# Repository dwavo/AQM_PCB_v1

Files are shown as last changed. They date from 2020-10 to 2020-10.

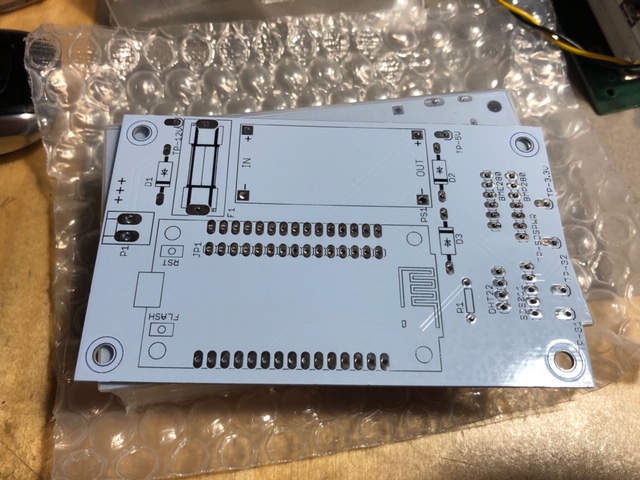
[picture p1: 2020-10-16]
robins egg boards.jpeg

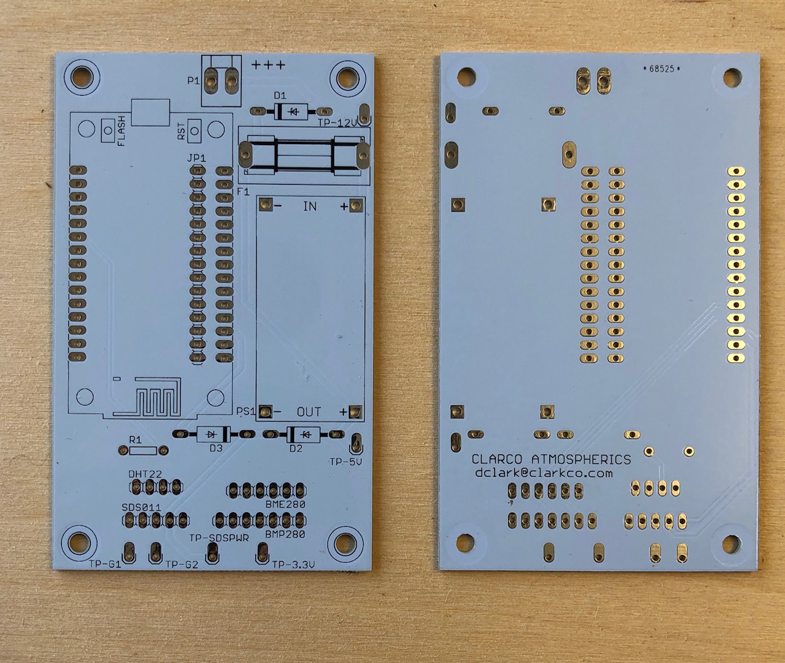
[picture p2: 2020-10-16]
pcb front back.jpg

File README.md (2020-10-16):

# AQM_PCB_v1

Thu Oct 15 19:47:02 PDT 2020

printed circuit board from kevin - sent to china for production.  We did version zero on an 'other mill'.  It proved to be a little too fickle. 

This is the first commercially spun pcb board for AQM luft.data project, now known as sensor community: https://sensor.community/ 

CA design PCB-v1 supports NodeMCUv2 and NodeMCUv3 esp8266 microcontroller.  

Set up with DHT and SDS011 sensors, also supports BM*280; and PMSx003 series sniffers.  P1 allows soldering screw terminals or pigtail, with positive shown as +++.  

Top diode (D1) is for reverse polarity protection.  Fusex at .25 Amp.  dc:buck (LM2596) allows external power source of  9-24V dc source (old wall warts) for long runs (over 5 meters).  This solves the potential low voltage problem of driving the 5v fan on the SDS011.  

Using two 1A 40V Shottky diodes (D2,D3) to protect computer if usb and external power are applied at the same time. Test points added for ground, 5v and 3.3v.  

When building these, adjust the lM2596 to 5v at the test point.  Put black fingernail polish or hot glue and label the power converter "5V".    

A second version is contemplated, which will allow mounting the SDS011 on the same board.   
 
comments: dclark@clarkco.com

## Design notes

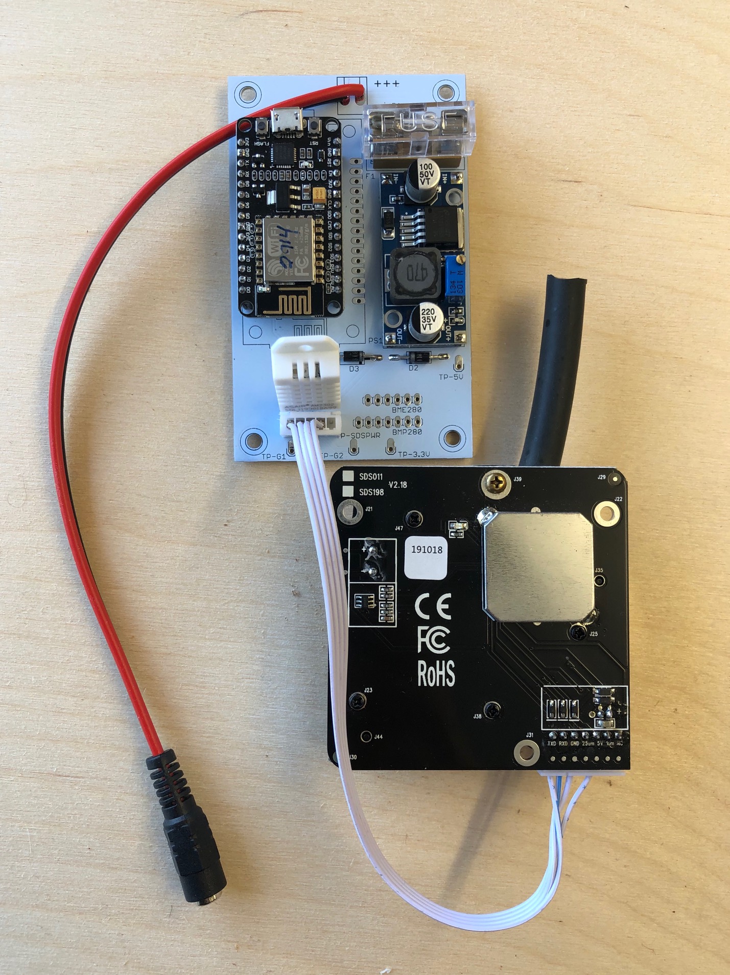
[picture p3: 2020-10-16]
pcb 2.jpg

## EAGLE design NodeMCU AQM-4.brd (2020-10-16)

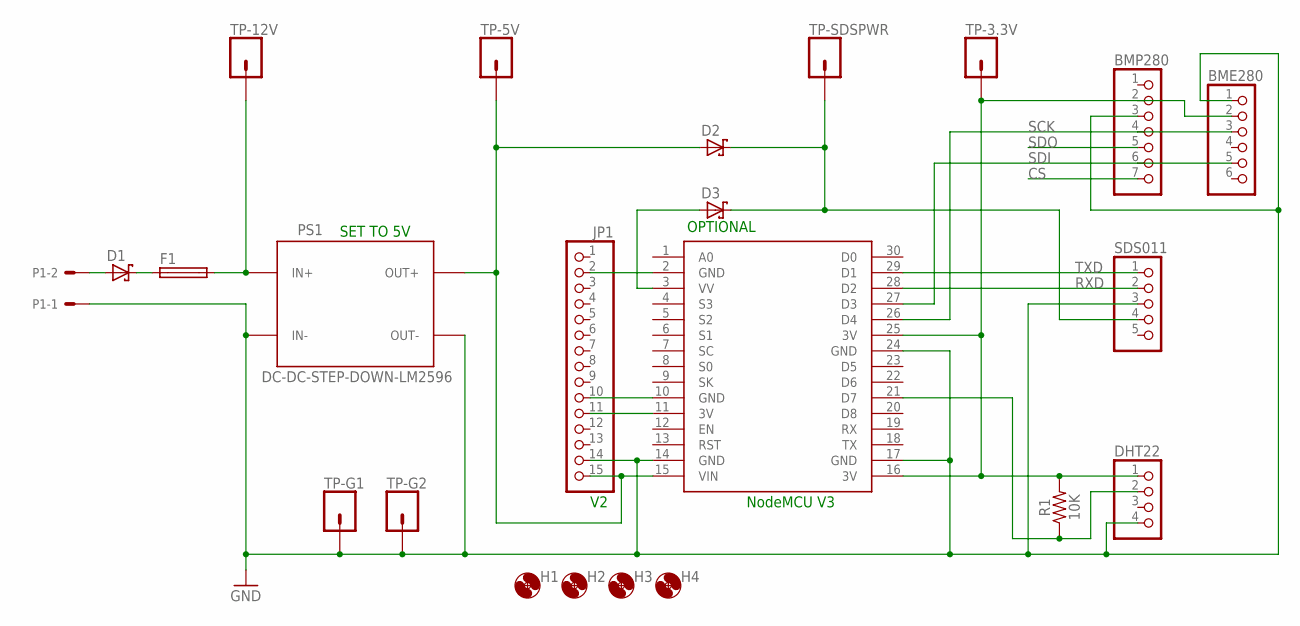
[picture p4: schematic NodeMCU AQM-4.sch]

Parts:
BME280: PINHD-1X6; 1X06
BMP280: PINHD-1X7; 1X07
D1, D2, D3: SCHOTTKY-DIODEF126Z12; DIODE_F126Z12
DHT22: PINHD-1X4; 1X04
F1: SH22,5A
H1, H2, H3, H4: MOUNT-HOLE3.6; 3,6
JP1: PINHD-1X15; 1X15
P1: KK-156-2
PS1: DC-DC-STEP-DOWN-LM2596
R1: 10K; AXIAL-0.3
SDS011: PINHD-1X5; 1X05
TP-3.3V, TP-5V, TP-12V: CONN_01OFFSET; 1X01_OFFSET
TP-G1, TP-G2: CONN_01OFFSET; 1X01_OFFSET
TP-SDSPWR: CONN_01OFFSET; 1X01_OFFSET
U$1: NODEMCU

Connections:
3V3: BME280.2, BMP280.2, DHT22.1, JP1.11, R1.P$2 (2), TP-3.3V.1, U$1.11 (3V), U$1.16 (3V), U$1.25 (3V)
CS: BMP280.7
GND: BME280.1, BMP280.3, DHT22.4, JP1.2, JP1.10, JP1.14, P1.1, PS1.IN-, PS1.OUT-, SDS011.3, TP-G1.1, TP-G2.1, U$1.2 (GND), U$1.10 (GND), U$1.14 (GND), U$1.17 (GND), U$1.24 (GND)
unnamed: D2.A (C), JP1.15, PS1.OUT+, TP-5V.1, U$1.15 (VIN)
unnamed: D3.A (C), U$1.3 (VV)
unnamed: D1.A (C), P1.2
unnamed: D1.C (A), F1.1
unnamed: F1.2, PS1.IN+, TP-12V.1
unnamed: DHT22.2, R1.P$1 (1), U$1.21 (D7)
RXD: SDS011.2, U$1.28 (D2)
SCK: BME280.3, BMP280.4, U$1.26 (D4)
SDI: BME280.5, BMP280.6, U$1.27 (D3)
SDO: BMP280.5
SDSPWR: D2.C (A), D3.C (A), SDS011.4, TP-SDSPWR.1
TXD: SDS011.1, U$1.29 (D1)

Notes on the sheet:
SET TO 5V
NodeMCU V3
OPTIONAL

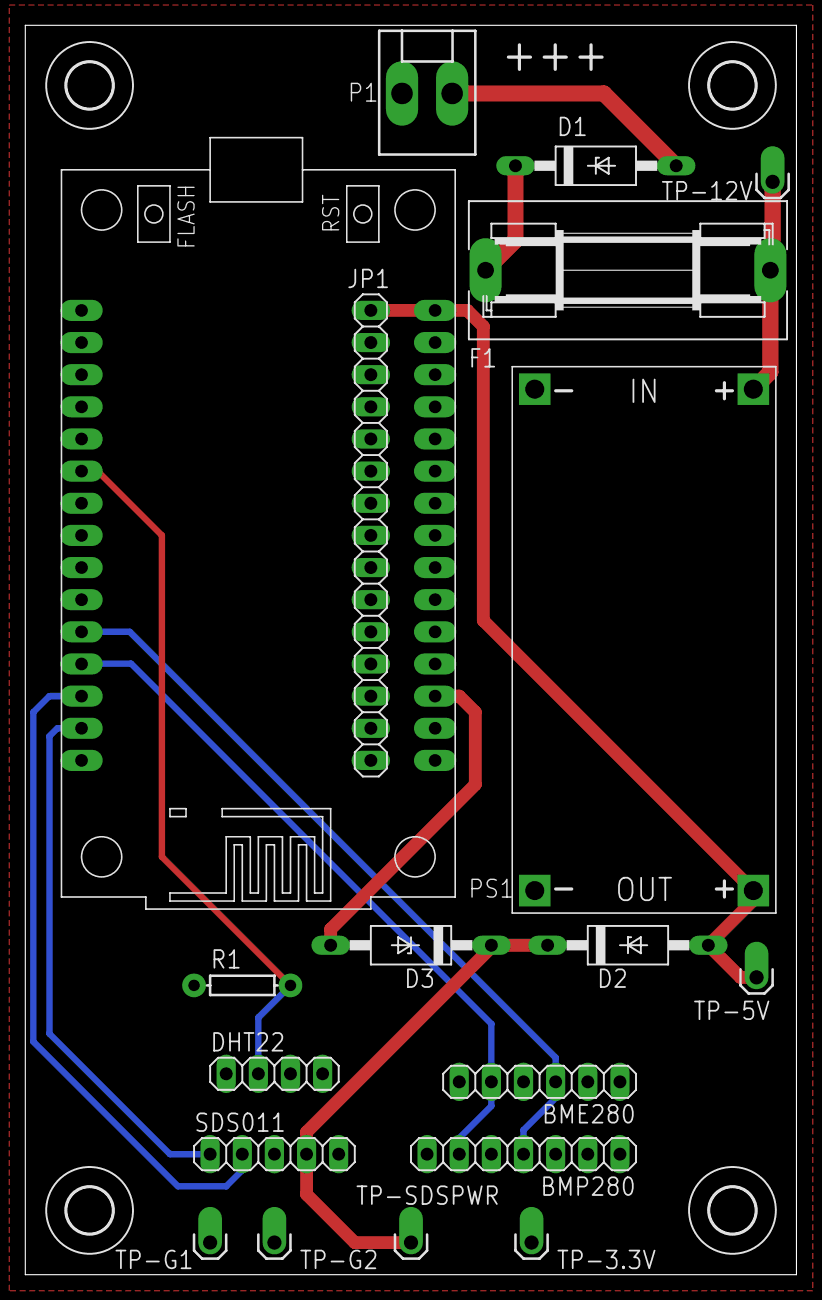
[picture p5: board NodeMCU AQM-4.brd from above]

Board: 2 copper layers, 60.9 x 98.7 mm, 23 parts (0 on the bottom side), 13 nets.

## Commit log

2020-10-16 PCB_v1
    Initial build sent to china
    [NodeMCU AQM-4.brd, NodeMCU AQM-4.sch]
2020-10-16 pcb board schematics to send out for mfg
    printed circuit board for esp8266 nodeMCU sensor.community luftdata.info

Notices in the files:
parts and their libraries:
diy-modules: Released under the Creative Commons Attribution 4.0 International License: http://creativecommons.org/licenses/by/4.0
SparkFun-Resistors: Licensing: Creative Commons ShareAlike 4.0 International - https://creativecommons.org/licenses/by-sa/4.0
